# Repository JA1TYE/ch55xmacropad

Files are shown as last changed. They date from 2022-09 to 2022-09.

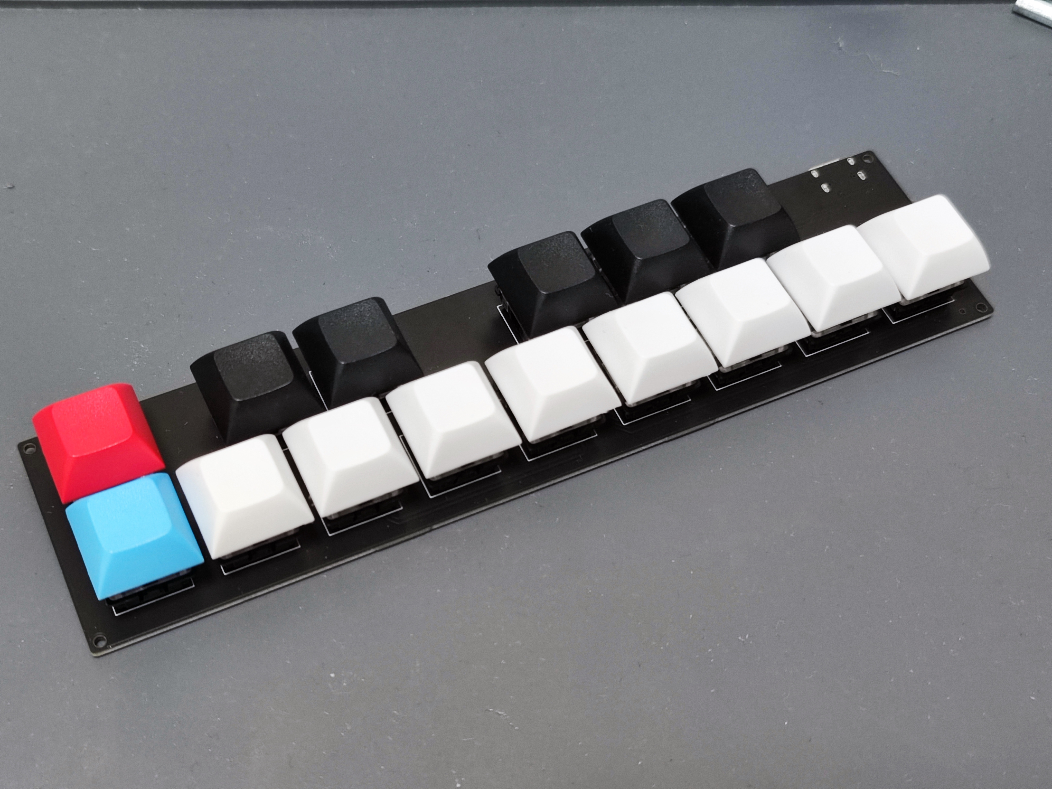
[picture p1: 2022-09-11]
docs/pic.jpg

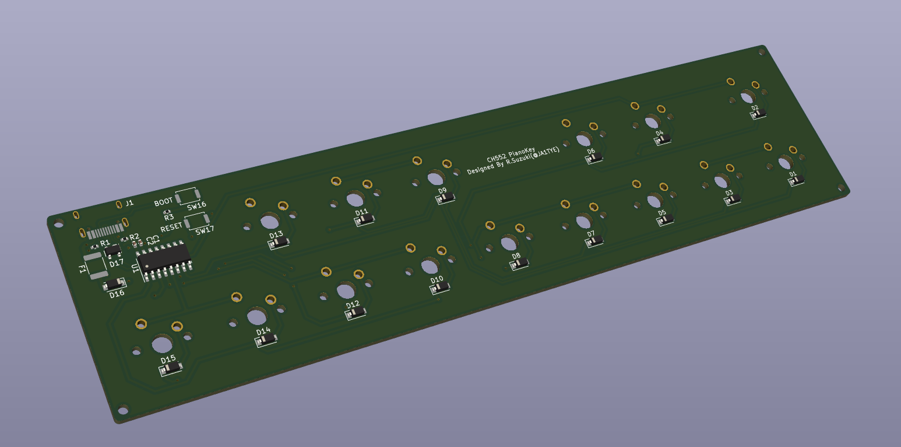
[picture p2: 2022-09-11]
docs/KiCAD_Render.png

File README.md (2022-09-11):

# CH55xで作るマクロパッド

## 概要
[#MakePCBA 第2回](https://makepcba02.peatix.com/)で紹介した15キーのマクロパッドの設計データです。

## ディレクトリ構成
- docs/:README用の画像など
- firmware/:キーボード用のファームウェアです。[CH55xduino](https://github.com/DeqingSun/ch55xduino)用のスケッチファイルになっています。
- hardware/pcb/:回路図と基板、部品実装用のデータです。KiCAD用です。

## ライセンス
LGPL-2.1ライセンスに従います。

- firmware/ディレクトリのソースのうちch55xmacropad.inoはCH55xduinoのサンプルスケッチをベースにしています。
- firmware/src/内のソースはCH55xduinoのサンプルスケッチに付属のソースをそのまま流用しています。

## 作者
- JA1TYE/Ryota Suzuki([@JA1TYE](https://twitter.com/JA1TYE))
- Webサイト：[https://t-techlab.com](https://t-techlab.com)

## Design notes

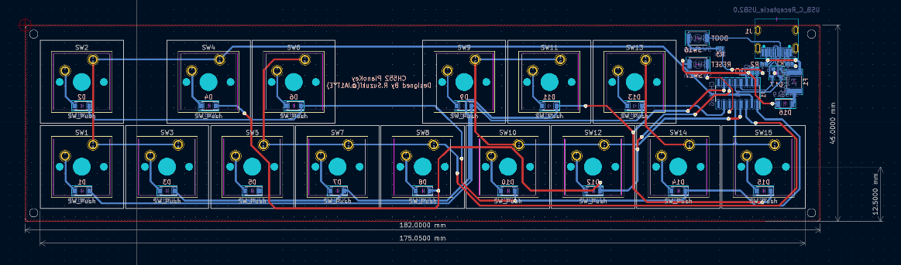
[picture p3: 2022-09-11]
docs/kicad_pcb.png

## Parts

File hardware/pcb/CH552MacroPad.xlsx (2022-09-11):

Comment | Designator | Footprint | LCSC
0.1u | C1,C2 | 0402 | C1525
1N5819 | D1,D2,D3,D4,D5,D6,D7,D8,D9,D10,D11,D12,D13,D14,D15,D16 | SOD-123 | C117948
SP0503BAHT | D17 | SOT-143 | C7074
mSMD110 | F1 | 1812 | C66450
USB_C_Receptacle_USB2.0 | J1 | SuLibs:USB_C_2.0 | C165948
5.1k | R1,R2 | 0402 | C25905
10k | R3 | 0402 | C25744
SW_Push | SW16,SW17 | Button_Switch_SMD:SW_Push_SPST_NO_Alps_SKRK | C115357
CH55xG | U1 | Package_SO:SOIC-16_3.9x9.9mm_P1.27mm | C114295

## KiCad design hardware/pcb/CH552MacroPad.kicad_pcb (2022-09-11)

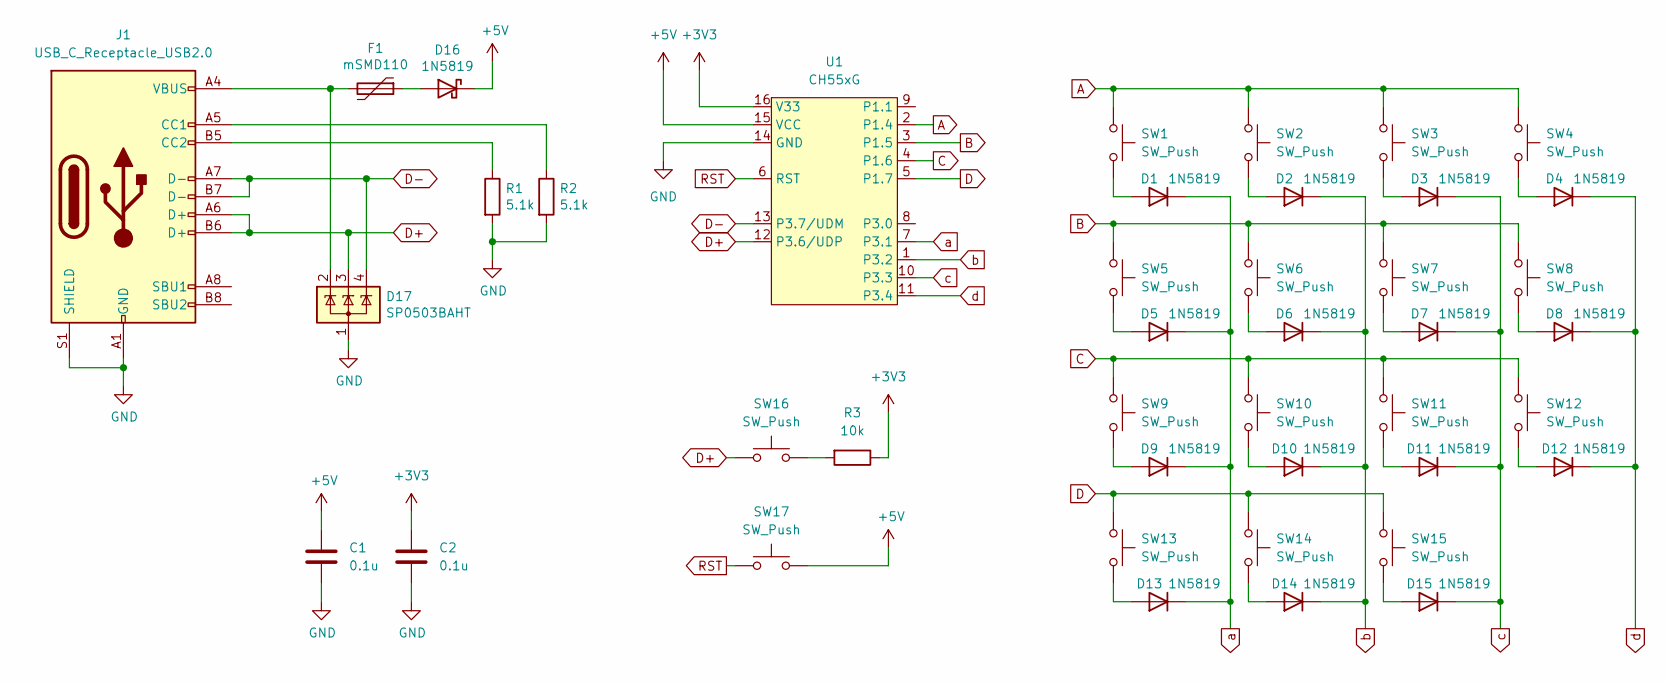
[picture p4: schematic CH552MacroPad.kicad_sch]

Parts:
C1, C2: 0.1u; C_0402_1005Metric
D1, D2, D3, D4, D5, D6, D7, D8, D9, D10, D11, D12, D13, D14, D15, D16: 1N5819; D_SOD-123
D17: SP0503BAHT; SOT-143
F1: mSMD110; Fuse_1812_4532Metric
J1: USB_C_Receptacle_USB2.0; USB_C_2.0
R1, R2: 5.1k; R_0402_1005Metric
R3: 10k; R_0402_1005Metric
SW1, SW2, SW3, SW4, SW5, SW6, SW7, SW8, SW9, SW10, SW11, SW12, SW13, SW14, SW15: SW_Push; SW_Cherry_MX_1.00u_PCB
SW16, SW17: SW_Push; SW_Push_SPST_NO_Alps_SKRK
U1: CH55xG; SOIC-16_3.9x9.9mm_P1.27mm

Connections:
+3V3: C2.1, R3.1, U1.16 (V33)
+5V: C1.1, D16.1 (K), SW17.2, U1.15 (VCC)
A: SW1.1, SW2.1, SW3.1, SW4.1, U1.2 (P1.4)
B: SW5.1, SW6.1, SW7.1, SW8.1, U1.3 (P1.5)
C: SW9.1, SW10.1, SW11.1, SW12.1, U1.4 (P1.6)
D: SW13.1, SW14.1, SW15.1, U1.5 (P1.7)
D+: D17.3 (K), J1.A6 (D+), J1.B6 (D+), SW16.1, U1.12 (P3.6/UDP)
D-: D17.4 (K), J1.A7 (D-), J1.B7 (D-), U1.13 (P3.7/UDM)
GND: C1.2, C2.2, D17.1 (A), J1.A1 (GND), J1.A12 (GND), J1.B1 (GND), J1.B12 (GND), J1.S1 (SHIELD), R1.2, R2.2, U1.14 (GND)
unnamed: D1.2 (A), SW1.2
unnamed: D2.2 (A), SW2.2
unnamed: D3.2 (A), SW3.2
unnamed: D4.2 (A), SW4.2
unnamed: D5.2 (A), SW5.2
unnamed: D6.2 (A), SW6.2
unnamed: D7.2 (A), SW7.2
unnamed: D8.2 (A), SW8.2
unnamed: D9.2 (A), SW9.2
unnamed: D10.2 (A), SW10.2
unnamed: D11.2 (A), SW11.2
unnamed: D12.2 (A), SW12.2
unnamed: D13.2 (A), SW13.2
unnamed: D14.2 (A), SW14.2
unnamed: D15.2 (A), SW15.2
unnamed: D16.2 (A), F1.1
unnamed: D17.2 (K), F1.2, J1.A4 (VBUS), J1.A9 (VBUS), J1.B4 (VBUS), J1.B9 (VBUS)
unnamed: J1.A5 (CC1), R2.1
unnamed: J1.B5 (CC2), R1.1
unnamed: R3.2, SW16.2
RST: SW17.1, U1.6 (RST)
a: D1.1 (K), D5.1 (K), D9.1 (K), D13.1 (K), U1.7 (P3.1)
b: D2.1 (K), D6.1 (K), D10.1 (K), D14.1 (K), U1.1 (P3.2)
c: D3.1 (K), D7.1 (K), D11.1 (K), D15.1 (K), U1.10 (P3.3)
d: D4.1 (K), D8.1 (K), D12.1 (K), U1.11 (P3.4)

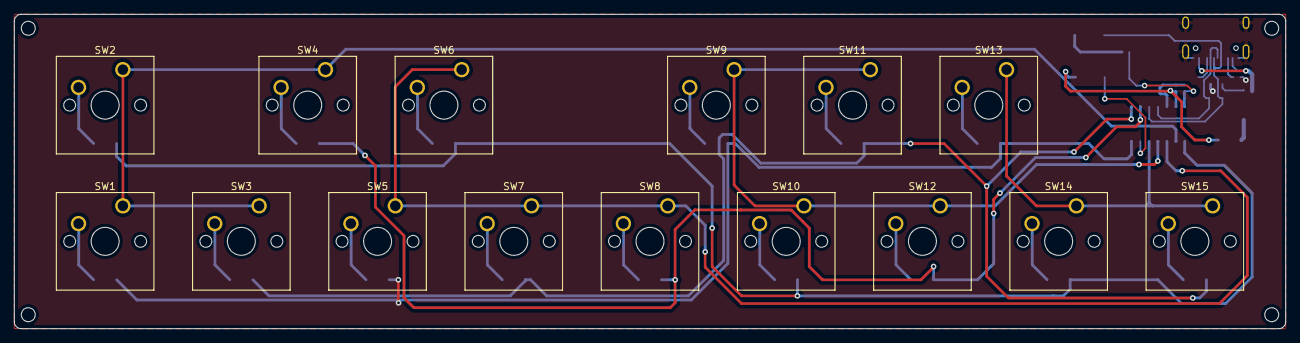
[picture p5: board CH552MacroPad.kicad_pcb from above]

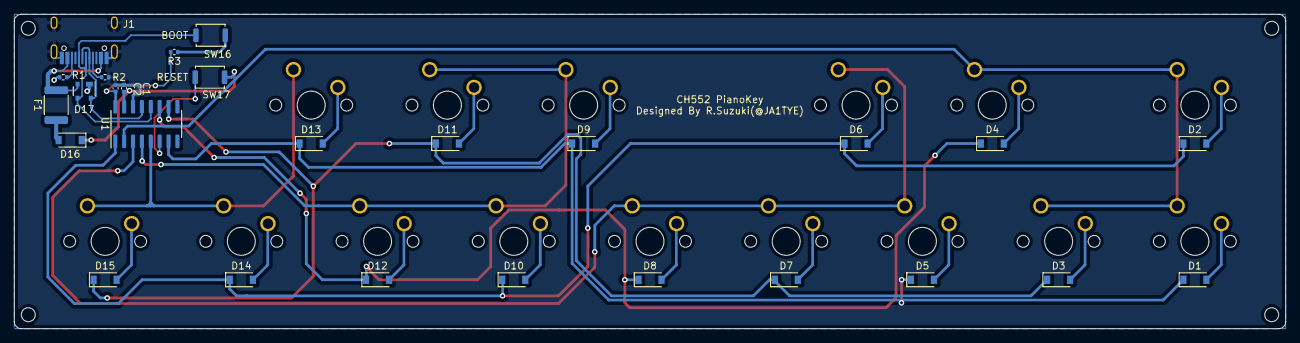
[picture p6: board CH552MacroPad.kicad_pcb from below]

Board: 2 copper layers, 182.0 x 45.0 mm, 42 parts (27 on the bottom side), 34 nets.

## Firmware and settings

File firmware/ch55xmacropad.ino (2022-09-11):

/*
 * 
 * CH55x Macropad Example
 * Based on HIDkeyboard example (https://github.com/DeqingSun/ch55xduino)
 * 
 */


#ifndef USER_USB_RAM
#error "This example needs to be compiled with a USER USB setting"
#endif

#include "src/userUsbHidKeyboard/USBHIDKeyboard.h"

/*
 * Pin Assignment
 * 
 * ROW A (Input) :P1.4/14
 * ROW B (Input) :P1.5/15
 * ROW C (Input) :P1.6/16
 * ROW D (Input) :P1.7/17
 * 
 * COL a (Output):P3.1/31
 * COL b (Output):P3.2/32
 * COL c (Output):P3.3/33
 * COL d (Output):P3.4/34
 * 
 */

#define ROW_A 14
#define ROW_B 15
#define ROW_C 16
#define ROW_D 17

#define COL_a 31
#define COL_b 32
#define COL_c 33
#define COL_d 34

const uint8_t colTable[4] = {COL_a,COL_b,COL_c,COL_d};
const char keymap[16] = {
  'z','w','5','7',
  'x','3','t','u',
  'q','e','6','i',
  '2','r','y','p'
  };

bool keyPrev[16];
bool keyCurrent[16];

void selectCol(uint8_t col){
  switch(col){
    case COL_a:
      digitalWrite(COL_a,LOW);
      digitalWrite(COL_b,HIGH);
      digitalWrite(COL_c,HIGH);
      digitalWrite(COL_d,HIGH);
      break;
    case COL_b:
      digitalWrite(COL_a,HIGH);
      digitalWrite(COL_b,LOW);
      digitalWrite(COL_c,HIGH);
      digitalWrite(COL_d,HIGH);
      break;
    case COL_c:
      digitalWrite(COL_a,HIGH);
      digitalWrite(COL_b,HIGH);
      digitalWrite(COL_c,LOW);
      digitalWrite(COL_d,HIGH);
      break;
    case COL_d:
      digitalWrite(COL_a,HIGH);
      digitalWrite(COL_b,HIGH);
      digitalWrite(COL_c,HIGH);
      digitalWrite(COL_d,LOW);
      break;
    default:
      digitalWrite(COL_a,HIGH);
      digitalWrite(COL_b,HIGH);
      digitalWrite(COL_c,HIGH);
      digitalWrite(COL_d,HIGH);            
  }
}

void setup() {
  uint8_t i;
  
  USBInit();
  
  //Row
  pinMode(ROW_A, INPUT_PULLUP);
  pinMode(ROW_B, INPUT_PULLUP);
  pinMode(ROW_C, INPUT_PULLUP);
  pinMode(ROW_D, INPUT_PULLUP);
  
  //Column  
  pinMode(COL_a, OUTPUT);
  pinMode(COL_b, OUTPUT);
  pinMode(COL_c, OUTPUT);
  pinMode(COL_d, OUTPUT);

  selectCol(COL_a);

  for(i = 0;i < 16;i++){
    keyPrev[i] = false;
    keyCurrent[i] = false;
  }
}

void loop() {
  uint8_t i;

  //Read key status
  for(i = 0;i < 4;i++){
    selectCol(colTable[i]);
    delay(1);
    keyCurrent[i * 4]     = !digitalRead(ROW_A);
    keyCurrent[i * 4 + 1] = !digitalRead(ROW_B);
    keyCurrent[i * 4 + 2] = !digitalRead(ROW_C);
    keyCurrent[i * 4 + 3] = !digitalRead(ROW_D);
  }

  //Check press/release
  for(i = 0;i < 15;i++){
    if(keyPrev[i] != keyCurrent[i]){
      if(keyCurrent[i] == true){
        Keyboard_press(keymap[i]);
      }
      else{
        Keyboard_release(keymap[i]);
      }
      keyPrev[i] = keyCurrent[i];
    }
  }
  
  delay(50);  //naive debouncing

}
